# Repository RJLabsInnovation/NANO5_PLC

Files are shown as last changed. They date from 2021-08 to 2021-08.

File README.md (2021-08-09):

NANO5_PLC
===========
  Design and (C) 2021 RJLabs Innovation <rjlabs.innovation@gmail.com> 
  
  Provided under the terms of the CC0 1.0 Universal license.

Overview
--------
  This design board is based Outseal PLC V.5 [Outseal Website](http://www.outseal.com/web/produk). The main goal of this project to provide sigle side PCB that can be produce in house using transfer paper or negatif film method.

Key Feature
-------- 
* Buitlin Modbus RTU
* Bultin external EEPROM 24CXX
* Isolated Digital Input (12V - 24V)
* 2 Relay On Board with Surge Protection
* Add On RTC DS3231 & Bluethoot HC05/06 

TODO
--------
* Add Regulator input power From LDO using Switching fore wide input voltage
* 

FINAL PRODUCT 3D RENDER
--------

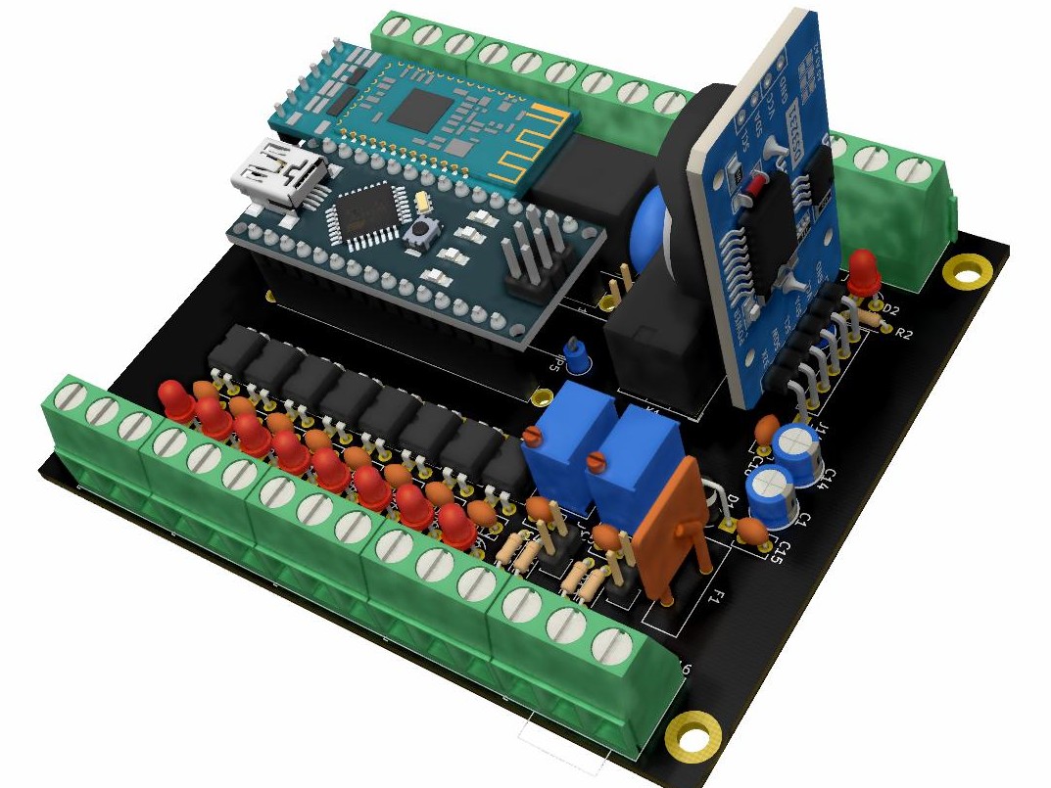
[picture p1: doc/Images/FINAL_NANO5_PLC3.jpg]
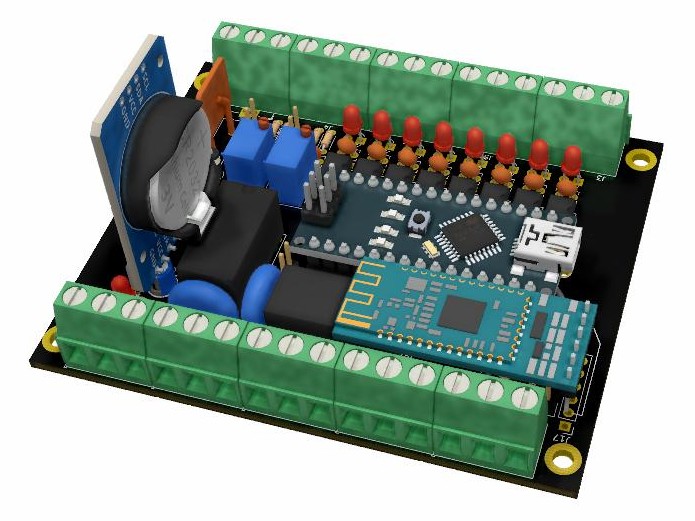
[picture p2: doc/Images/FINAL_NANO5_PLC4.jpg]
  

Donations
--------
To support this project, you can make a donation to its current maintainer:

paypal (https://paypal.me/auto70)
bitcoin-black

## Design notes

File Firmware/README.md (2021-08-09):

# NANO5_PLC COMPATIBLE FIRMWARE

This board is base Arduino Nano 328, can be programmed using software like :

*1. Arduino IDE
*2. codevision AVR
*3. Atmel Studio
*4. another programming tool compatible with Atmega328

# PLC LIKE PROGRAMMING TOOLS

### [OUTSEAL PLC](http://www.outseal.com/web/download/)

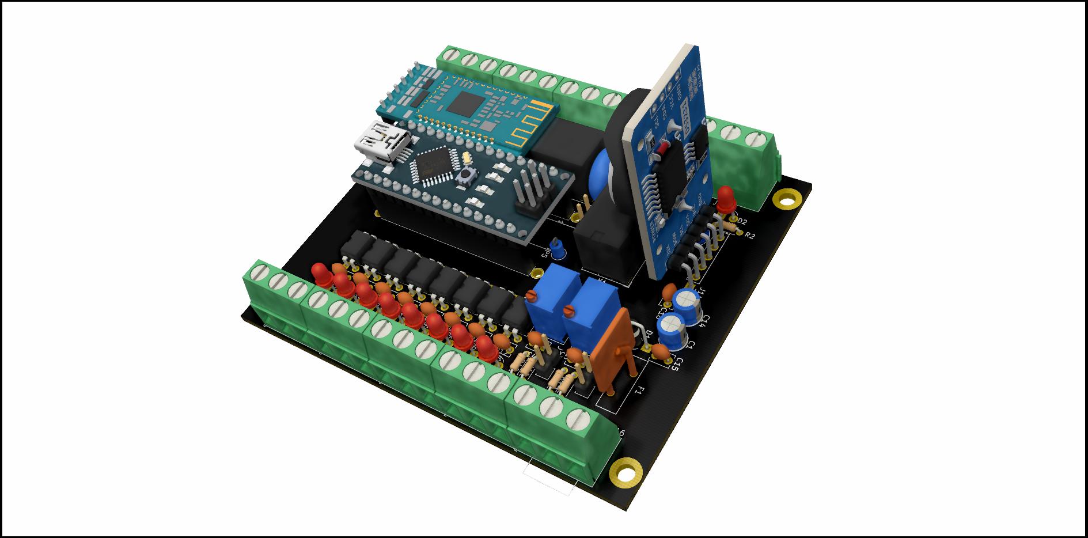
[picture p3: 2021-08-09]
doc/Images/FINAL_NANO5_PLC.jpg

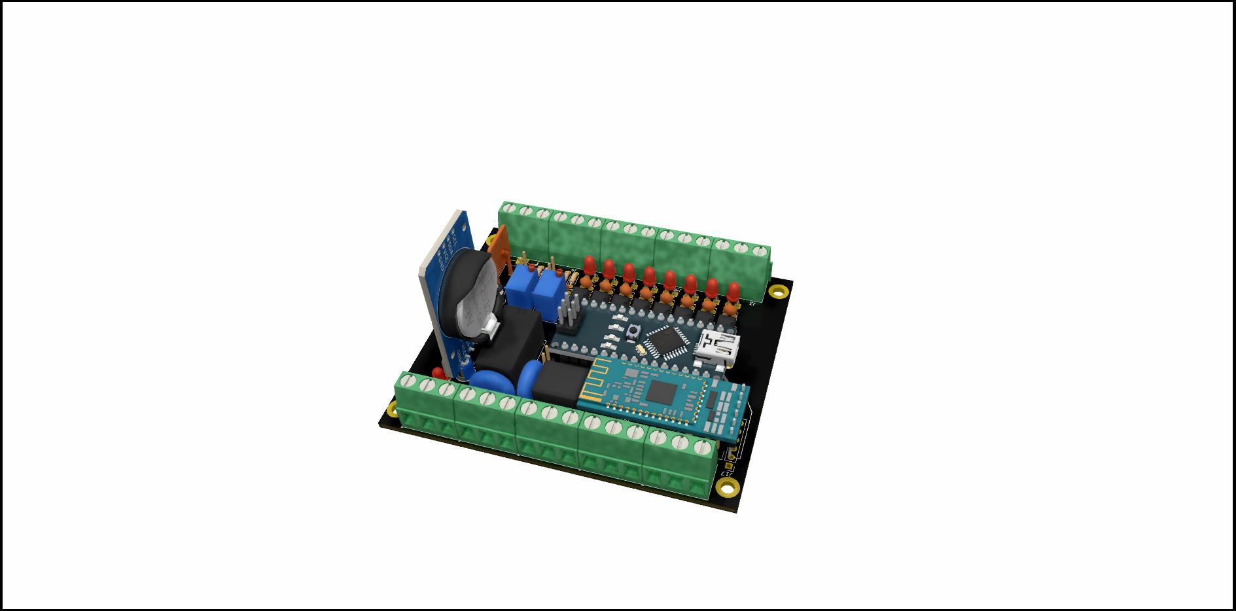
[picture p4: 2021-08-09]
doc/Images/FINAL_NANO5_PLC2.jpg

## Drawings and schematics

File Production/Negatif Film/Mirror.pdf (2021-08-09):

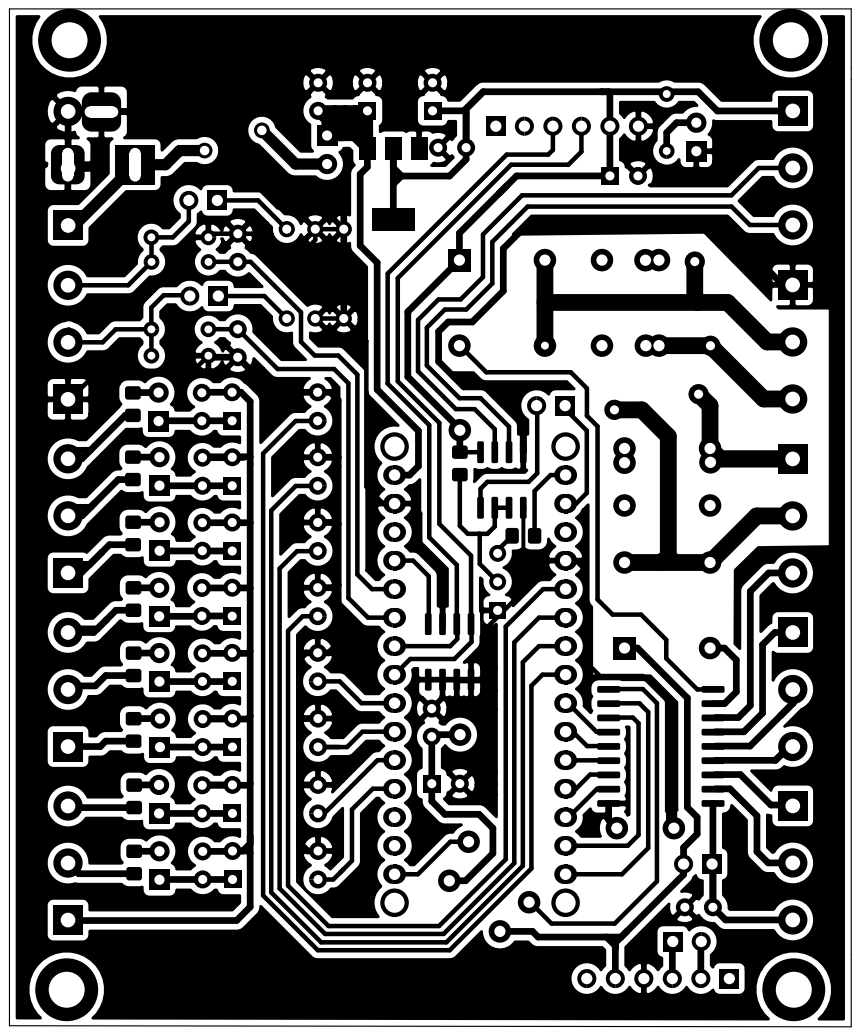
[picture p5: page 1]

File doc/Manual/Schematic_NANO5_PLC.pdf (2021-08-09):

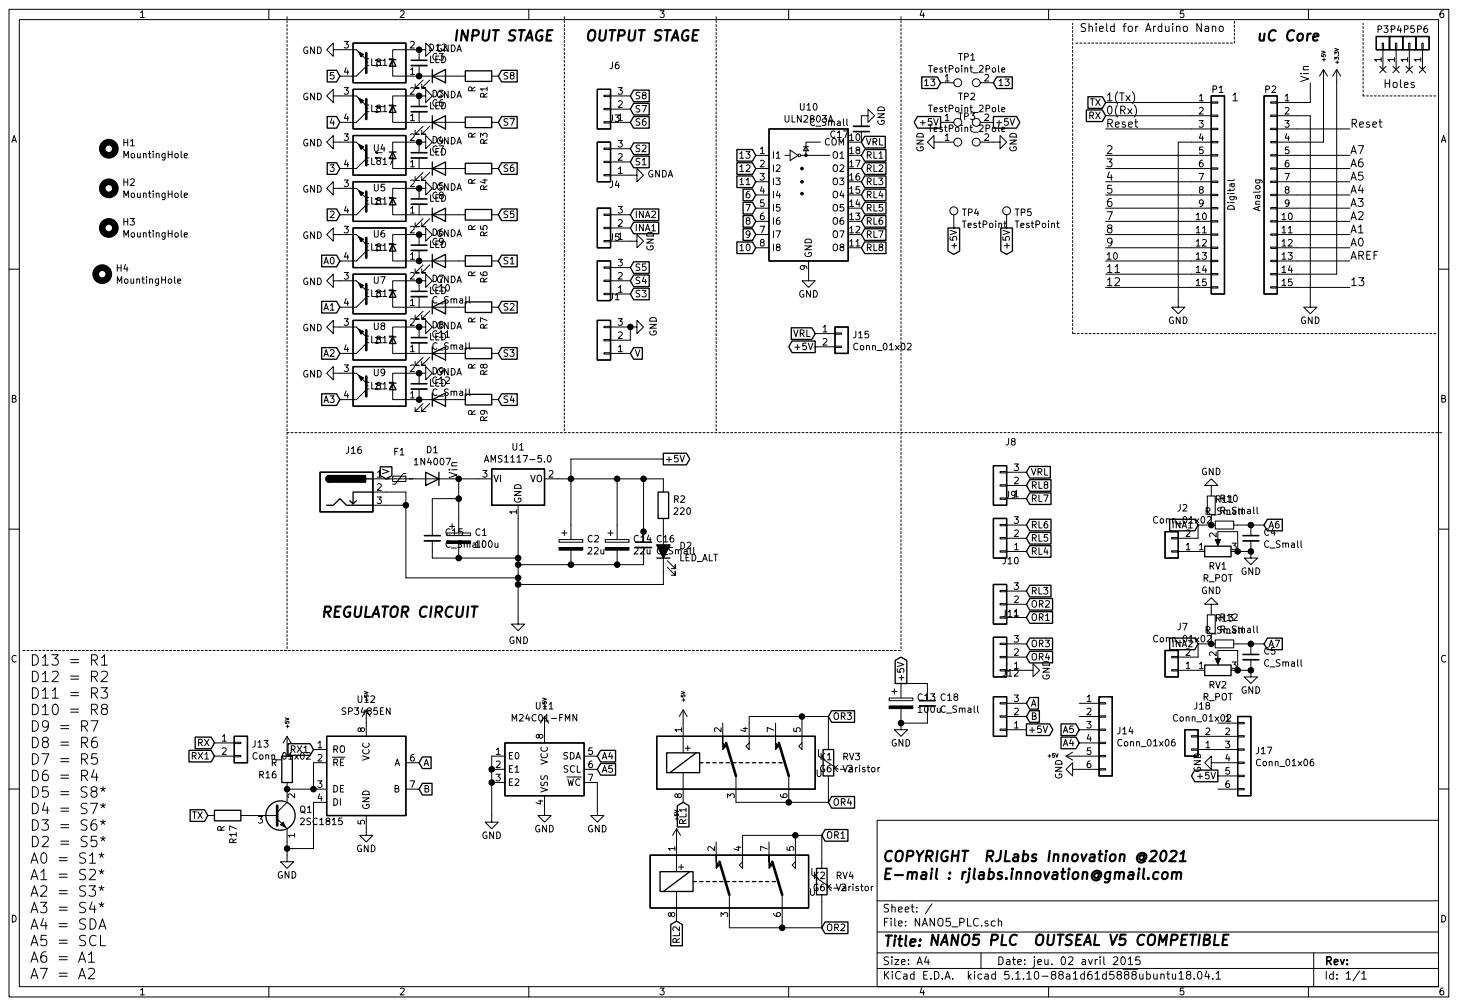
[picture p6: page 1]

4 SDA 5 SCL 6 WC 7 VCC

COPYRIGHT RJLabs Innovation @2021
E-mail : rjlabs.innovation@gmail.com

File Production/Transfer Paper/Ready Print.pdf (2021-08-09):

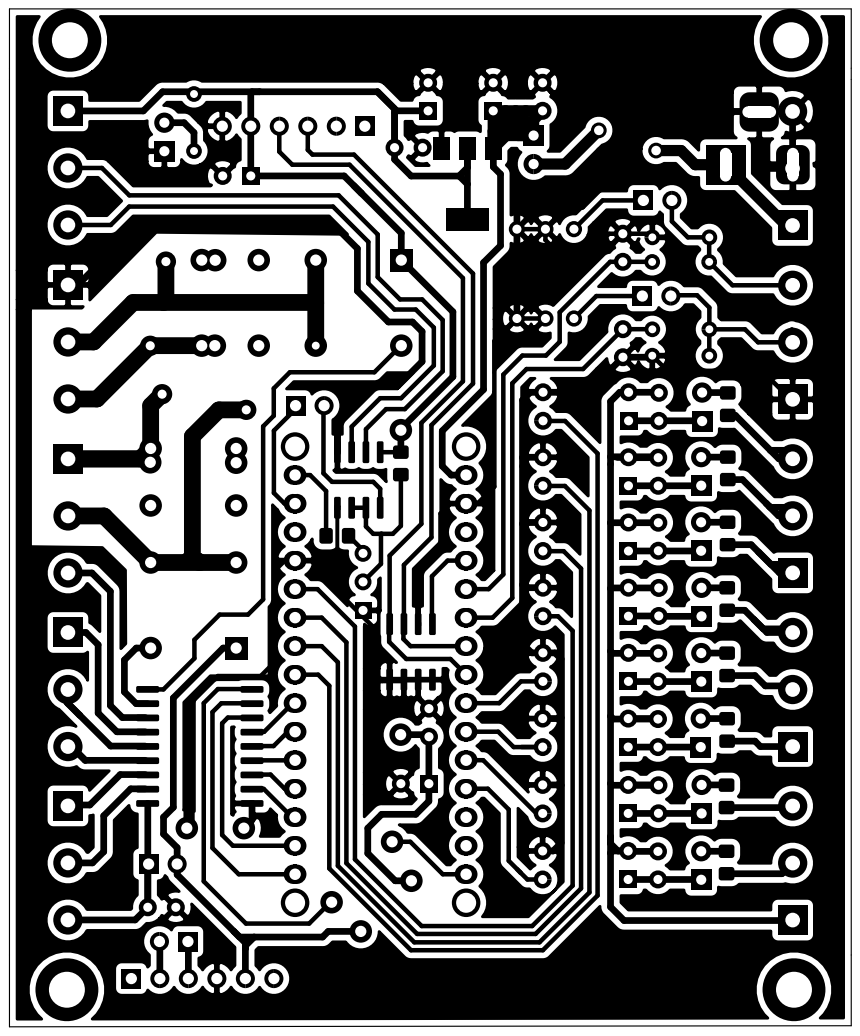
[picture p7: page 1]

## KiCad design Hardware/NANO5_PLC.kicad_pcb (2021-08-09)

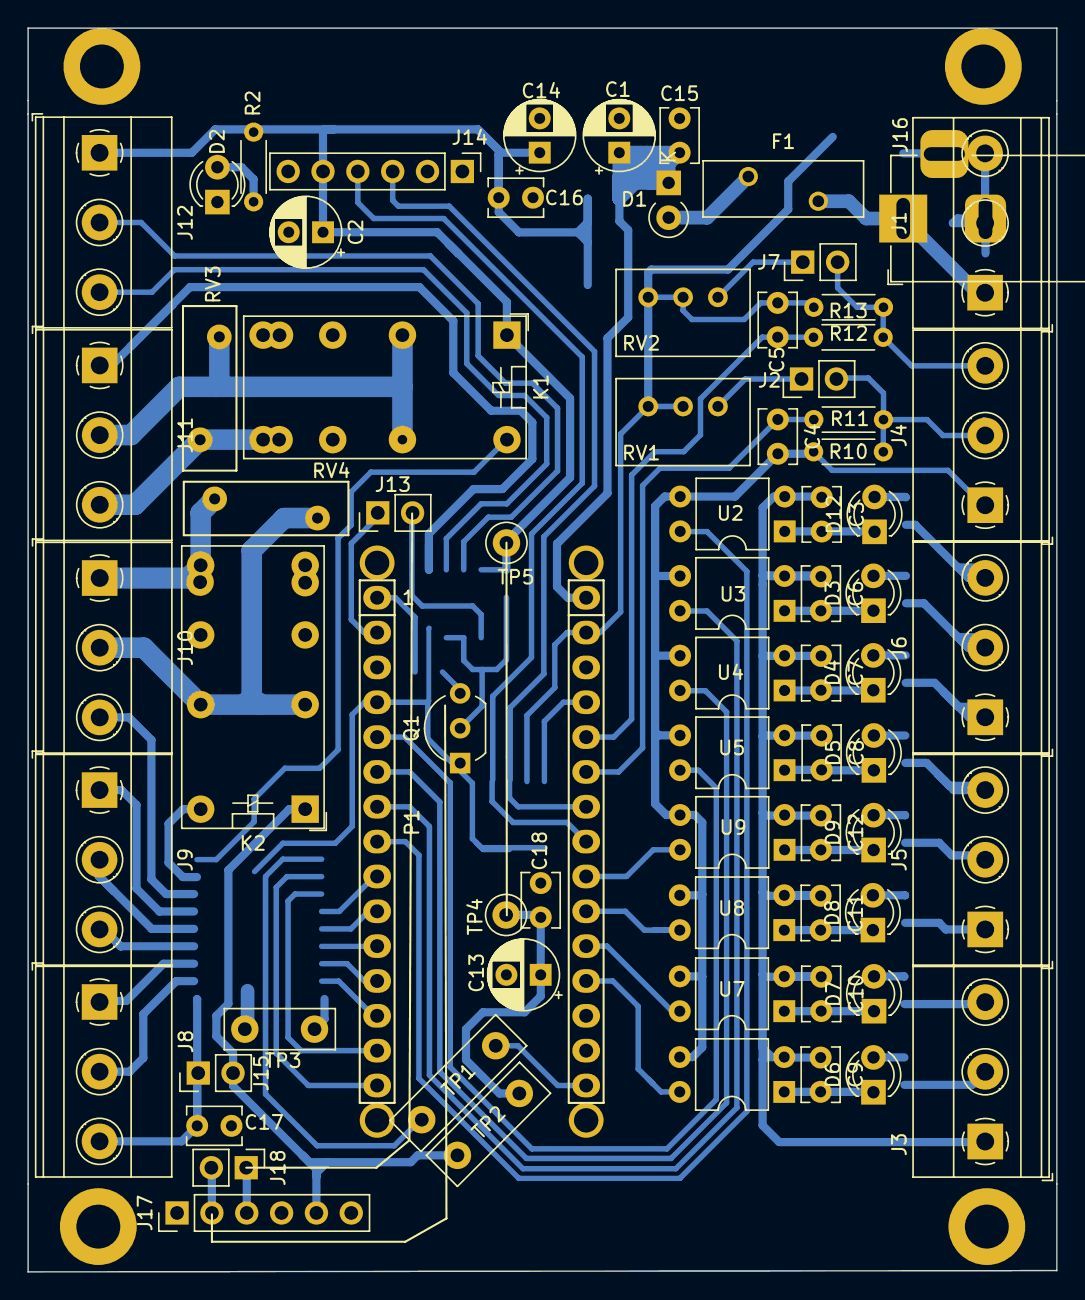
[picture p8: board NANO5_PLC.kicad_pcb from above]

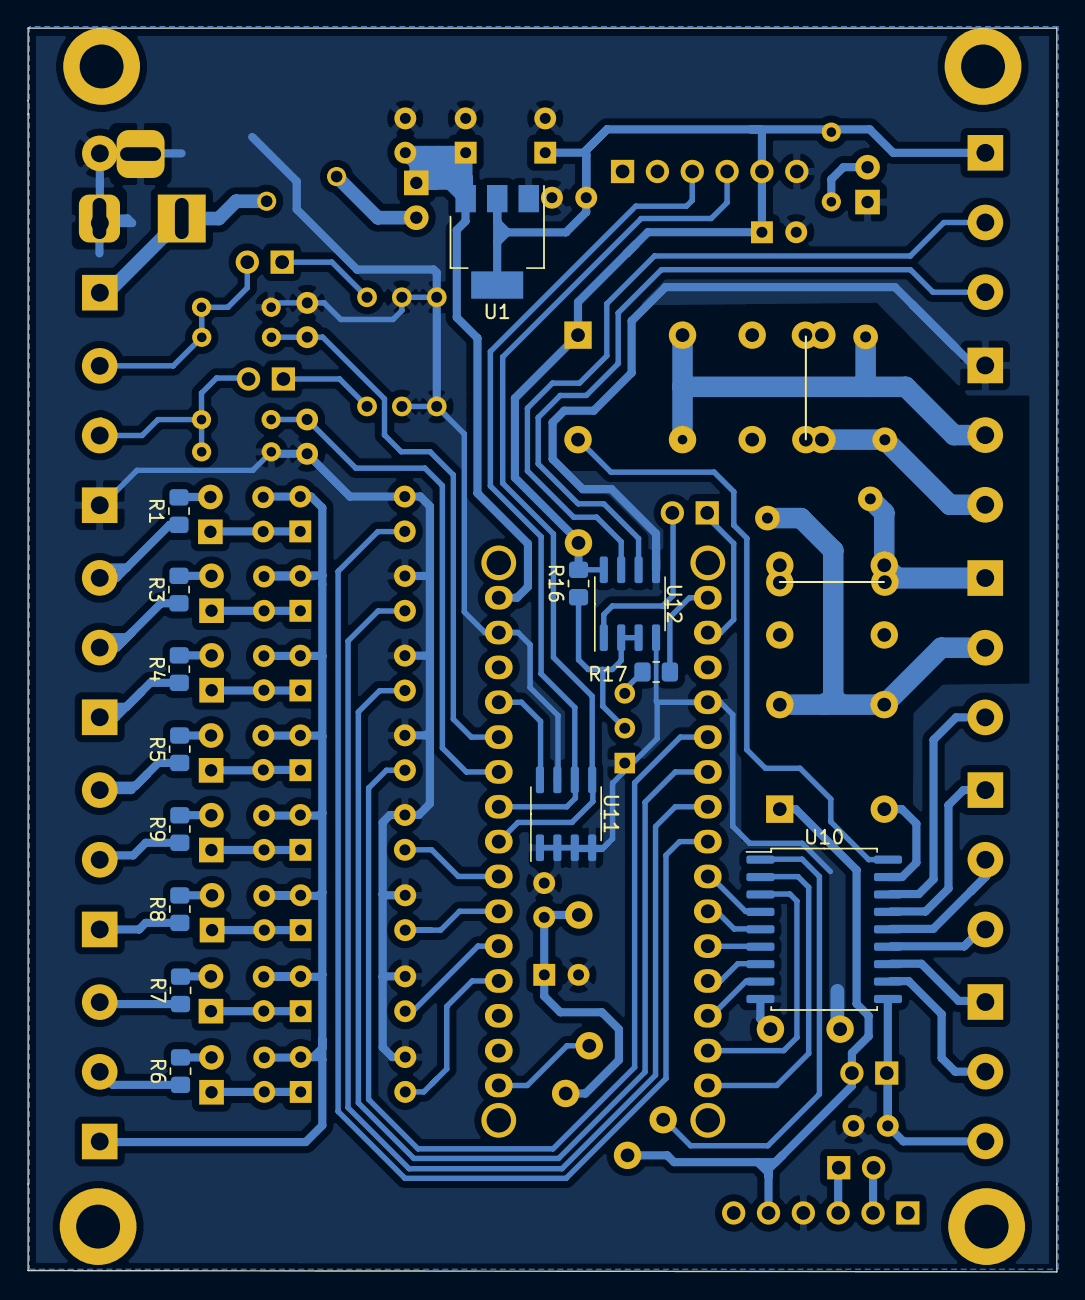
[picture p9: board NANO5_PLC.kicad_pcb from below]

Board: 2 copper layers, 75.0 x 90.7 mm, 96 parts (14 on the bottom side), 78 nets.

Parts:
C1, C13: 100u; CP_Radial_D5.0mm_P2.50mm
C2, C14: 22u; CP_Radial_D5.0mm_P2.50mm
C3, C4, C5, C6, C7, C8, C9, C10, C11, C12, C15, C16, C17, C18: C_Small; C_Disc_D3.8mm_W2.6mm_P2.50mm
D1: 1N4007; D_A-405_P2.54mm_Vertical_KathodeUp
D2: LED_ALT; LED_D3.0mm
D3, D4, D5, D6, D7, D8, D9, D12: LED; LED_D3.0mm
F1: Polyfuse_Small; Fuse_BelFuse_0ZRE0033FF_L11.4mm_W3.8mm
H1, H2, H3, H4: MountingHole; MountingHole_3.2mm_M3_DIN965_Pad
J1, J3, J4, J5, J6, J8, J9, J10, J11, J12: Conn_01x03; TerminalBlock_Phoenix_MKDS-1,5-3-5.08_1x03_P5.08mm_Horizont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
J2, J7, J13, J15, J18: Conn_01x02; PinHeader_1x02_P2.54mm_Vertical
J14, J17: Conn_01x06; PinHeader_1x06_P2.54mm_Vertical
J16: Barrel_Jack_Switch_Pin3Ring; BarrelJack_Horizontal
K1, K2: G6K-2; Relay_DPDT_Omron_G5V-2
P1: Digital; Socket_Strip_Arduino_1x15
P2: Analog; Socket_Strip_Arduino_1x15
P3, P4, P5, P6: CONN_01X01; 1pin_Nano
Q1: 2SC1815; TO-92_Inline_Wide
R1, R3, R4, R5, R6, R7, R8, R9, R16, R17: R; R_0805_2012Metric_Pad1.20x1.40mm_HandSolder
R2: 220; R_Axial_DIN0204_L3.6mm_D1.6mm_P5.08mm_Horizontal
R10, R11, R12, R13: R_Small; R_Axial_DIN0204_L3.6mm_D1.6mm_P5.08mm_Horizontal
RV1, RV2: R_POT; Potentiometer_Bourns_3299W_Vertical
RV3, RV4: Varistor; RV_Disc_D12mm_W3.9mm_P7.5mm
TP1: TestPoint_2Pole; TestPoint_Bridge_Pitch7.62mm_Drill1.3mm
TP2: TestPoint_2Pole; TestPoint_Bridge_Pitch6.35mm_Drill1.3mm
TP3: TestPoint_2Pole; TestPoint_Bridge_Pitch5.08mm_Drill1.3mm
TP4, TP5: TestPoint; TestPoint_Loop_D1.80mm_Drill1.0mm_Beaded
U1: AMS1117-5.0; SOT-223-3_TabPin2
U2, U3, U4, U5, U6, U7, U8, U9: EL817; DIP-4_W7.62mm
U10: ULN2803A; SOIC-18W_7.5x11.6mm_P1.27mm
U11: M24C01-FMN; SOIC-8_3.9x4.9mm_P1.27mm
U12: SP3485EN; SOIC-8_3.9x4.9mm_P1.27mm

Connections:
2: P1.5, U5.4
3: P1.6, U4.4
4: P1.7, U3.4
5: P1.8, U2.4
6: P1.9, U10.4
7: P1.10, U10.5
8: P1.11, U10.6
9: P1.12, U10.7
10: P1.13, U10.8
11: P1.14, U10.3
12: P1.15, U10.2
13: P2.15, TP1.1, U10.1
+5V: C2.1, C13.1, C14.1, C16.1, C18.1, J12.1, J14.5, J15.2, J17.5, K1.1, K2.1, P2.4, R2.1, R16.2, TP2.1, TP4.1, TP5.1, U1.2, U11.8, U12.8
/Reset: P1.3, P2.3
/Vin: C1.1, C15.1, D1.1, P2.1, U1.3
A: J12.3, U12.6
A0: P2.12, U6.4
A1: P2.11, U7.4
A2: P2.10, U8.4
A3: P2.9, U9.4
A4: J14.4, P2.8, U11.5
A5: J14.3, P2.7, U11.6
A6: C4.1, P2.6, R11.1
A7: C5.1, P2.5, R13.1
B: J12.2, U12.7
GND: C1.2, C2.2, C4.2, C5.2, C13.2, C14.2, C15.2, C16.2, C17.2, C18.2, D2.1, J1.2, J1.3, J4.1, J11.1, J14.6, J16.2, J16.3, J17.4, P1.4, P2.2, Q1.1, R10.2, R12.2, RV1.2, RV1.3, RV2.2, RV2.3, TP3.1, U1.1, U2.3, U3.3, U4.3, U5.3, U6.3, U7.3, U8.3, U9.3, U10.9, U11.1, U11.2, U11.3, U11.4, U11.7, U12.4, U12.5
GNDA: C3.1, C6.1, C7.1, C8.1, C9.1, C10.1, C11.1, C12.1, J3.1, U2.2, U3.2, U4.2, U5.2, U6.2, U7.2, U8.2, U9.2
INA1: J2.2, J4.2, R10.1, R11.2
INA2: J4.3, J7.2, R12.1, R13.2
unnamed: C3.2, D12.1, U2.1
unnamed: C6.2, D3.1, U3.1
unnamed: C7.2, D4.1, U4.1
unnamed: C8.2, D5.1, U5.1
unnamed: C9.2, D6.1, U6.1
unnamed: C10.2, D7.1, U7.1
unnamed: C11.2, D8.1, U8.1
unnamed: C12.2, D9.1, U9.1
unnamed: D1.2, F1.1
unnamed: D2.2, R2.2
unnamed: D3.2, R3.2
unnamed: D4.2, R4.2
unnamed: D5.2, R5.2
unnamed: D6.2, R6.2
unnamed: D7.2, R7.2
unnamed: D8.2, R8.2
unnamed: D9.2, R9.2
unnamed: D12.2, R1.2
unnamed: J2.1, RV1.1
unnamed: J7.1, RV2.1
unnamed: J17.2, J18.2
unnamed: J17.3, J18.1
unnamed: Q1.2, R16.1, U12.2, U12.3
unnamed: Q1.3, R17.1
OR1: J10.1, K2.4, K2.5, RV4.1
OR2: J10.2, K2.3, K2.6, RV4.2
OR3: J11.3, K1.4, K1.5, RV3.1
OR4: J11.2, K1.3, K1.6, RV3.2
RL1: K1.8, U10.18
RL2: K2.8, U10.17
RL3: J10.3, U10.16
RL4: J9.1, U10.15
RL5: J9.2, U10.14
RL6: J9.3, U10.13
RL7: J8.1, U10.12
RL8: J8.2, U10.11
RX: J13.1, P1.2
RX1: J13.2, U12.1
S1: J3.2, R6.1
S2: J3.3, R7.1
S3: J5.1, R8.1
S4: J5.2, R9.1
S5: J5.3, R5.1
S6: J6.1, R4.1
S7: J6.2, R3.1
S8: J6.3, R1.1
TX: P1.1, R17.2
V: F1.2, J1.1, J16.1
VRL: C17.1, J8.3, J15.1, U10.10
